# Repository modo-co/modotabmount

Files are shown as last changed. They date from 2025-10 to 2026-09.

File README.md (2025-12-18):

# Modo Tab Mount

**Smart tablet wall mount with ESPHome firmware, magnetic docking, and configurable smart features.**

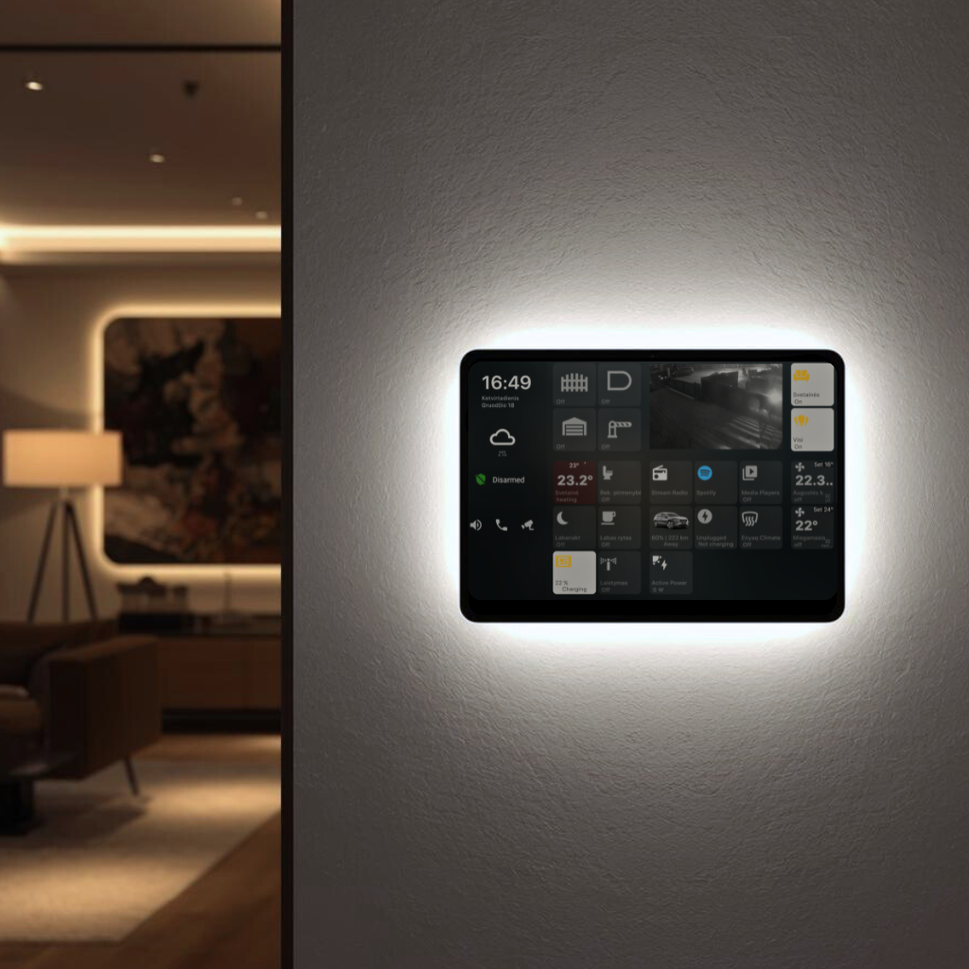
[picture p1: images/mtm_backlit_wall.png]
Modo Tab Mount – Wall mounted with ambient backlight


## Overview

**Modo Tab Mount** is a modular smart wall mount for tablets, designed for **standard flush EU electrical wall back boxes**.  
It combines a clean, floating design with integrated smart electronics and Home Assistant compatibility.

The project is suitable for **makers, home automation enthusiasts, and developers** who want a customizable and extensible tablet mounting solution.

## Features

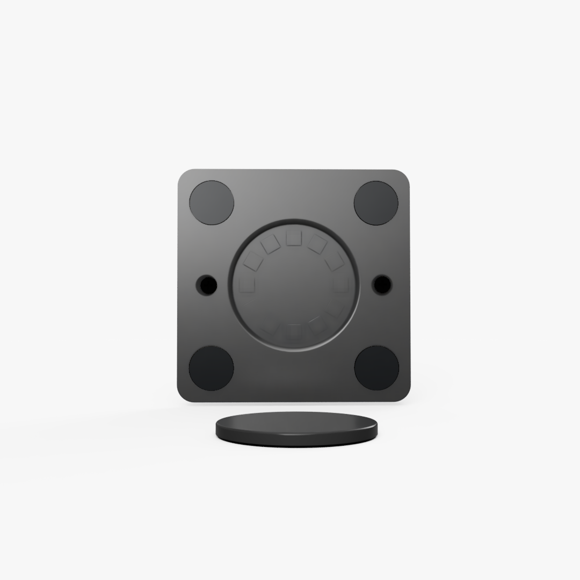
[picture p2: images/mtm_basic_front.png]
Modo Tab Mount – Front view


- **Magnetic Docking** – Secure, strong, snap-on mounting without mechanical locks  
- **Floating Design** – Minimal gap between tablet and wall  
- **Integrated Smart Power Supply** – 5V output for tablet charging and peripherals  
- **ESP32-based Controller** – Runs ESPHome firmware  
- **Backlit LEDs** – Optional WS2812B addressable LED bracket for status or ambient light  
- **Home Assistant Ready** – Native integration via ESPHome  
- **Expandable** – Support for additional sensors and peripherals  

## Hardware Components

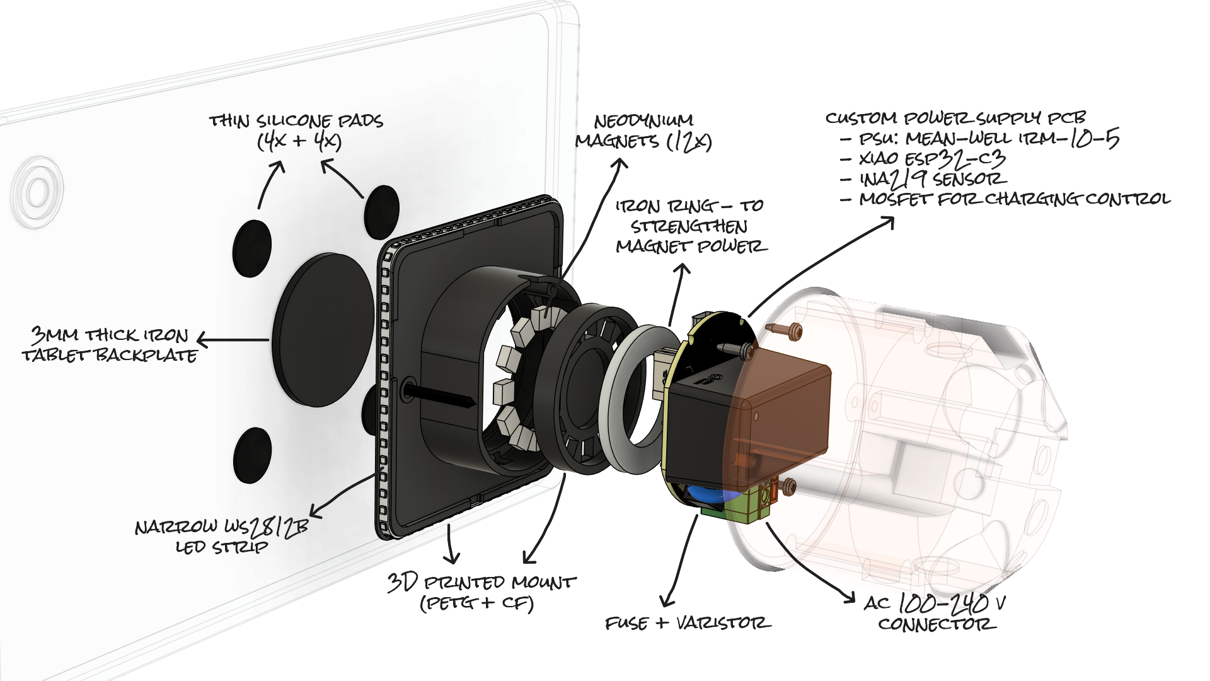
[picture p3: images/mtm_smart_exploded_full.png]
Modo Tab Mount – Exploded view


| Component | Description |
|---|---|
| Wall Box Mount | 3D-printed (PETG + CF filament) enclosure with embedded neodymium magnets / iron ring |
| Tablet Plate | 3 mm solid iron plate, attached using 3M VHB tape |
| Power Supply | Mean Well IRM-10-5 (5 V, 2 A) |
| PCB | Custom PCB for power distribution and peripheral connections |
| Microcontroller | Seeed Studio XIAO ESP32-C3 |
| LEDs | 2.7 mm WS2812B addressable LED strip |
| Charging Cable | Flat FPC cable with USB-C, Lightning, or Micro-USB connector |

## Repository Content

| Folder / File | Description |
|---|---|
| `PCB/` | Schematics and BOM for the custom PCB |
| `Docs/` | Installation instructions, datasheets, and technical documentation |
| `Images/` | Photos and diagrams |
| `modotabmount.yaml` | ESPHome firmware configuration |
| `README.md` | Project overview |
| `LICENSE` | License information |

## 📦 Firmware

**Modo Tab Mount** firmware runs on an **ESP32-C3** and is built using **ESPHome**.  
It provides charging control, power monitoring, Full LED RGB control with multiple built-in effects, and Home Assistant integration.

- Firmware is distributed as a **precompiled binary (`.bin`)** via **GitHub Releases**
- OTA updades with new firmware releases available
- End users **do not need to install ESPHome or compile firmware**
- ESPHome YAML file is included **for reference and advanced customization**

### 🔌 Smart Charging Control

- PWM-regulated 5V output for controlled tablet charging  
- Charging can be enabled or disabled remotely  
- During prolonged charging in a confined wall box, the power supply may warm up; firmware logic reduces or pauses charging to prevent excessive temperatures  

Charging state is exposed as a readable status  
(e.g. *Normal*, *Thermal throttling*, *Cooling down*).

### ⚡ Power & Energy Monitoring

An onboard **INA219** sensor measures:

- PSU Output voltage  
- PSU Output current  
- 30-second averaged values for stable reporting  

All values are available in **Home Assistant** and via the **built-in web interface**, enabling automations.

### 💡 LED Feedback & Ambient Lighting

Integrated **WS2812B LED strip** provides functional feedback and ambient lighting:

- Visual indication during **Wi-Fi access-point setup mode**
- Full RGB control with multiple built-in effects
- Automatic LED dimming during charging
- LED behavior configurable via Home Assistant or the local web interface

### 🌐 Connectivity & Interfaces

- Native **Home Assistant API** (ESPHome)
- Built-in **web interface** for local control and diagnostics
- **OTA firmware updates**
- **Bluetooth Proxy** support to extend Home Assistant BLE coverage

### ⚙️ Configuration & Diagnostics

User-configurable parameters include:

- Maximum temperature threshold
- Thermal throttle strength
- LED brightness during charging

Built-in diagnostics expose:

- Wi-Fi signal strength
- Device uptime
- Internal temperature
- Memory usage

A software-triggered factory reset is also available.

### 🔧 Advanced Usage

Advanced users may adopt device in ESPHome Builder, change YAML configuration and build custom firmware versions. 

---

## ⚠️ Safety Notice

This project involves **mains voltage (110–230 V AC)**.  Installation must be performed by qualified persons only.  

## 🏷 Commercial Product Note

This repository documents the **Modo Tab Mount project** and provides reference designs, firmware, and documentation intended for **makers and developers**.

A **commercially assembled Modo Tab Mount device**  offered separately by **MB Modoco**.  
Commercial units are:

- Assembled and tested by the manufacturer  
- Supplied with preinstalled firmware  
- Intended for end-user installation  
- Placed on the market under applicable EU conformity requirements  

The open-source materials in this repository are provided **for reference and non-commercial use** as defined by the applicable licenses.

## License

### Hardware (3D Models, Schematics, PCB Layouts)
Hardware designs in this repository are licensed under the  
**Creative Commons Attribution-NonCommercial 4.0 International (CC BY-NC 4.0)** license.

You may share and adapt these materials for **personal or educational use**.  
**Commercial manufacturing or resale is not permitted under this license.**

Full license text:  
https://creativecommons.org/licenses/by-nc/4.0/
### Firmware / Software
All firmware and software in this repository are licensed under the **MIT License**,  
allowing use, modification, and distribution, including for commercial purposes.

See the [LICENSE](./LICENSE) file for details.

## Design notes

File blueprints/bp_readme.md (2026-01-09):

## Tablet Charging Control

Automatically turns tablet charging **ON** when battery is low and **OFF** when
battery is high. Designed for wall-mounted tablets and smart chargers.

**Default behavior**
- Charging ON at **≤ 20%**
- Charging OFF at **≥ 80%**



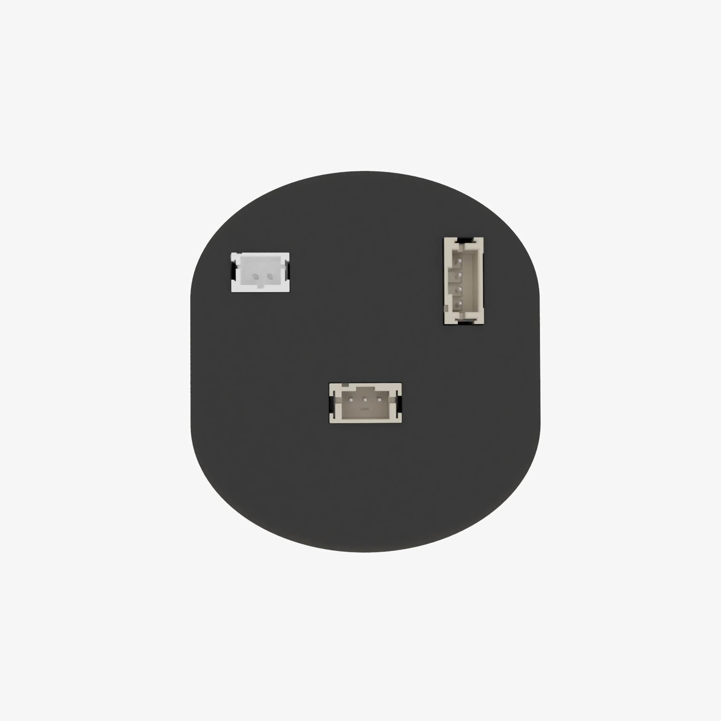
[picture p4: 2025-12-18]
images/psu_top.png

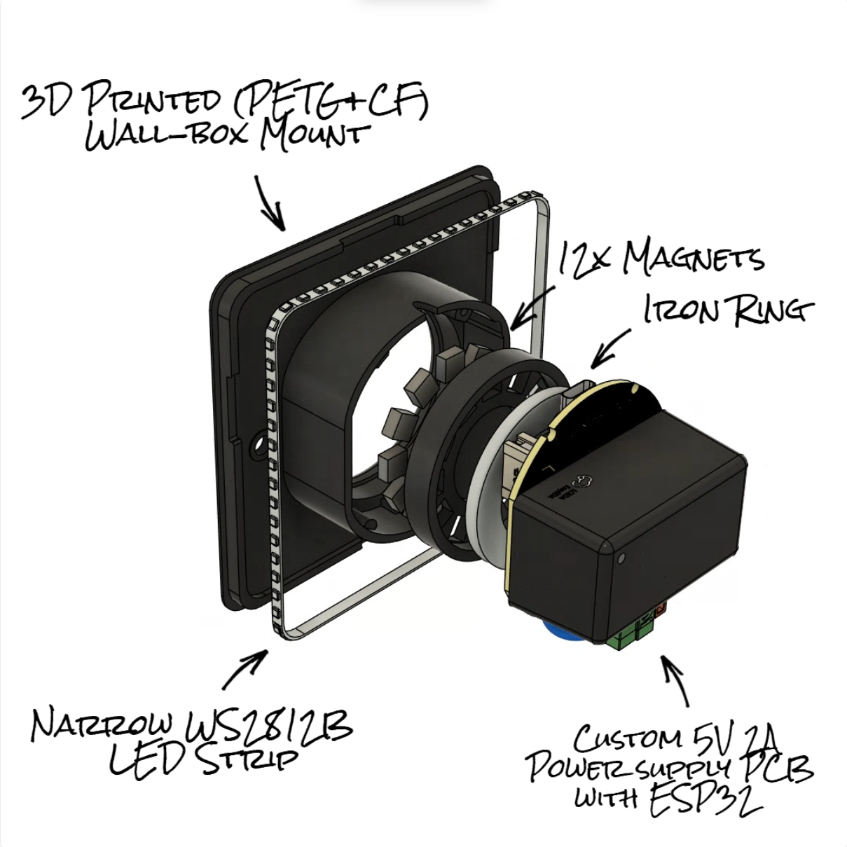
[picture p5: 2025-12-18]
images/mtm_smart_exploded.png

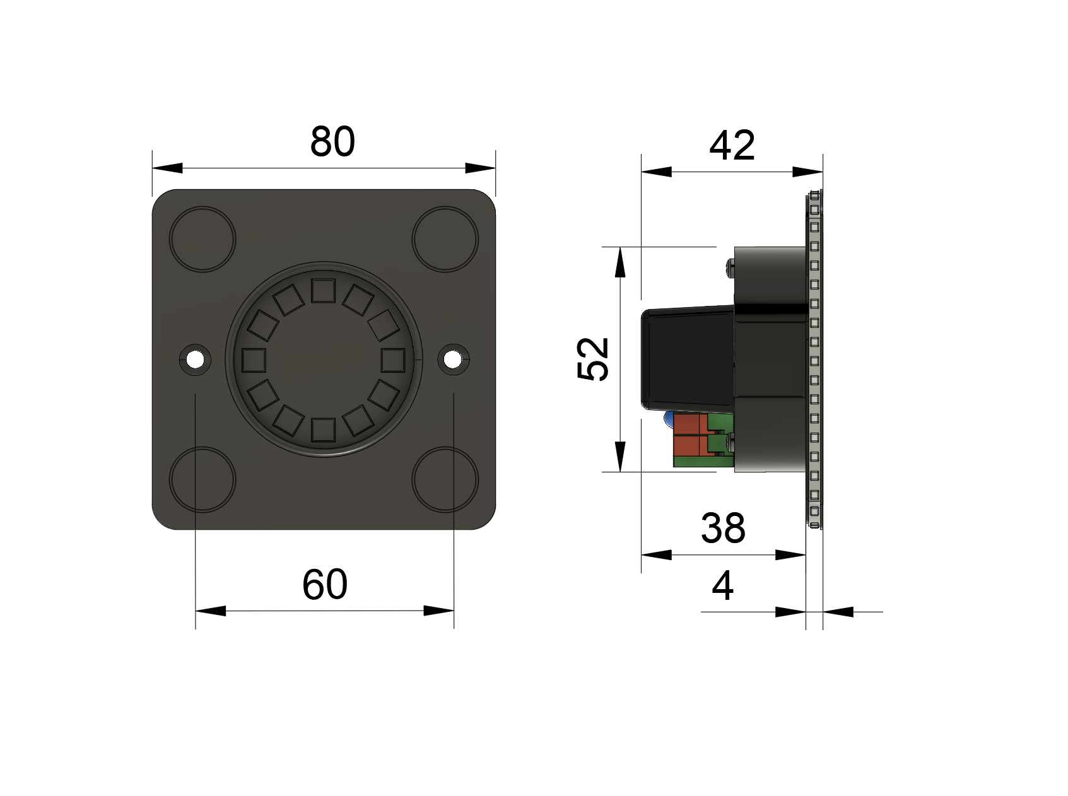
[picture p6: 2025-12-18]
images/mtm_smart_5.png

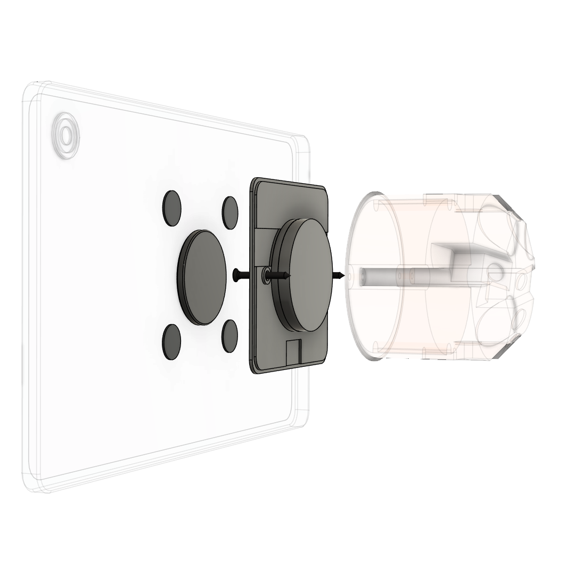
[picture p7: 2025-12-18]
images/mtm_basic_shaded.png

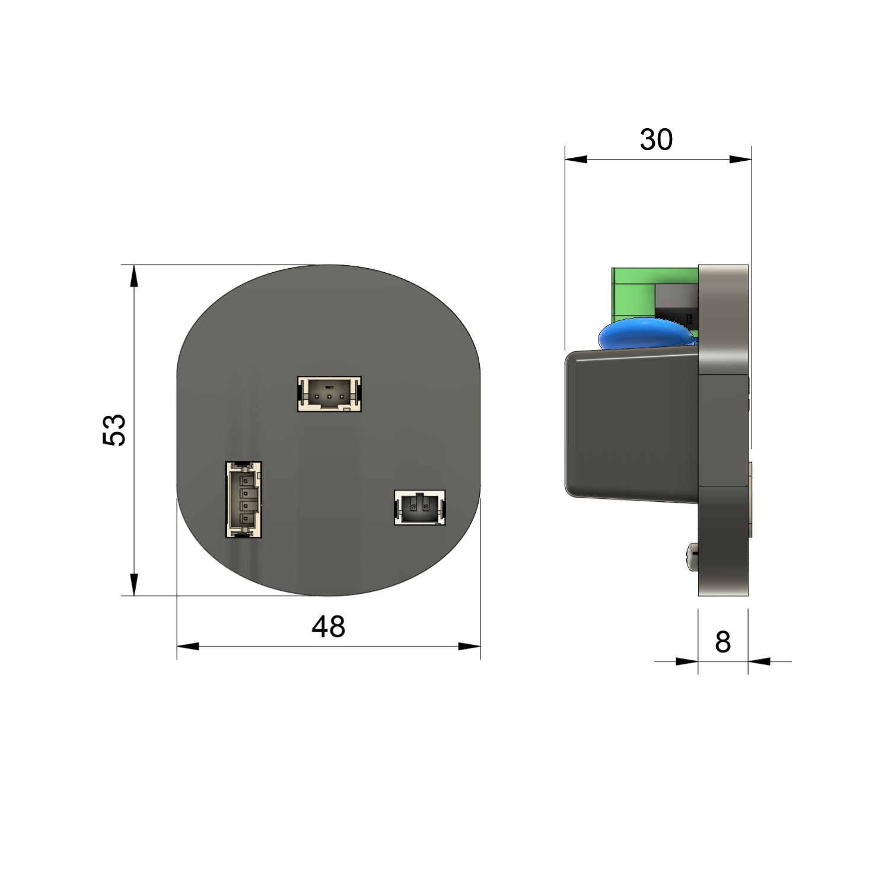
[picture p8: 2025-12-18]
images/psu_dimmensions.png

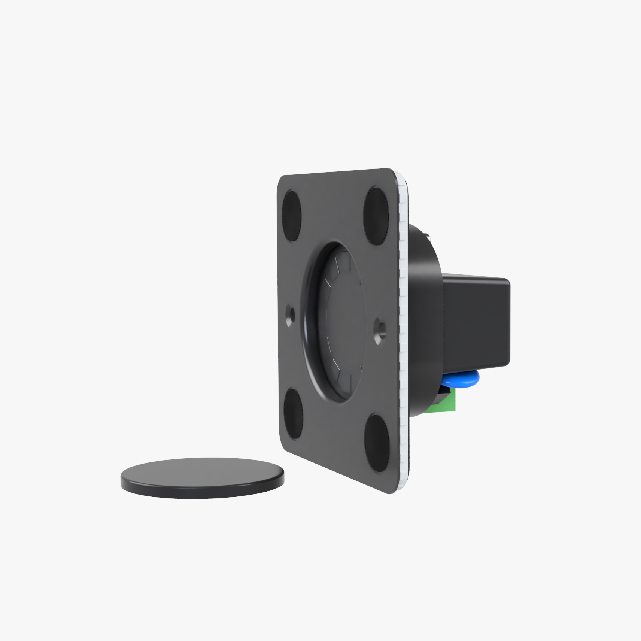
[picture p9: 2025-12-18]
images/mtm_smart_1.png

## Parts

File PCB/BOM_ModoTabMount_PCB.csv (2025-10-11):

ID | Name | Designator | Footprint | Quantity | Manufacturer Part
1 | XIAO ESP32C3 | U4 | COMM-SMD_KQ-2801_V106 | 1 | XIAO ESP32C3
2 | INA219AIDCNR | U2 | SOT-23-8 | 1 | INA219AIDCNR
3 | 10Kê | R1,R3 | 0805 | 2 | TC0550F1002T5E
4 | 0.1 | R5 | 2512 | 1 | MA251220JR100FZ
5 | 100nF | C1 | 0805 | 1 | 0805F104M101NT
6 | PH-4P | CONP_4PIN | CONN-SMD_PH2.0-4P | 1 | PH-4P
7 | 2.0-3P SMD 3P | CON_LEDS | CONN-SMD_3P-LT | 1 | PH-3P??
8 | AO3401A | Q1 | SOT-23_L2.9-W1.3-P1.90-LS2.4-BR | 1 | AO3401A
9 | MMBT3904 | Q2 | SOT-23-3_L2.9-W1.3-P1.90-LS2.4-BR | 1 | MMBT3904(RANGE:100-300)
10 | WAFER-PH2.0-2PLB | CHARGING | CONN-TH_2P-P2.00_XUNPU_WAFER-PH2.0-2PLB | 1 | WAFER-PH2.0-2PLB
11 | KF142V-5.08-2P | CON_AC | CONN-TH_P5.08_KF142V-5.08-2P | 1 | KF142V-5.08-2P
12 | MST 2A 250V | F2 | FUSE-TH_L8.4-W4.3-P5.08-D1.0 | 1 | MST 2A 250V
13 | CNR-10D561K | R10 | RES-TH_L12.5-W5.5-P7.50-D0.8-S5.50 | 1 | CNR-10D561K
14 | IRM-10-5 | U1 | PWRM-TH_4P-L45.7-W25.4-P8.0 | 1 | IRM-10-5

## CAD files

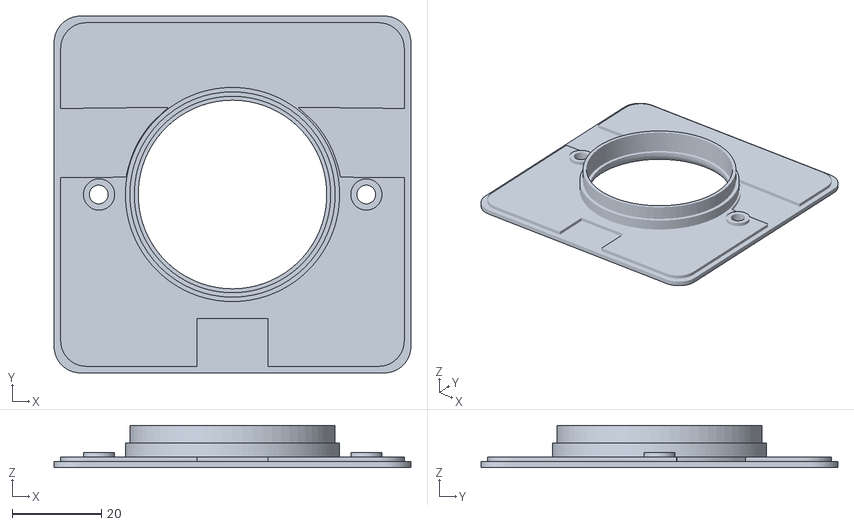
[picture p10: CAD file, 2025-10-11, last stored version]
3D_Models/mtm_plate_main.stl
80.0 x 80.0 x 9.50

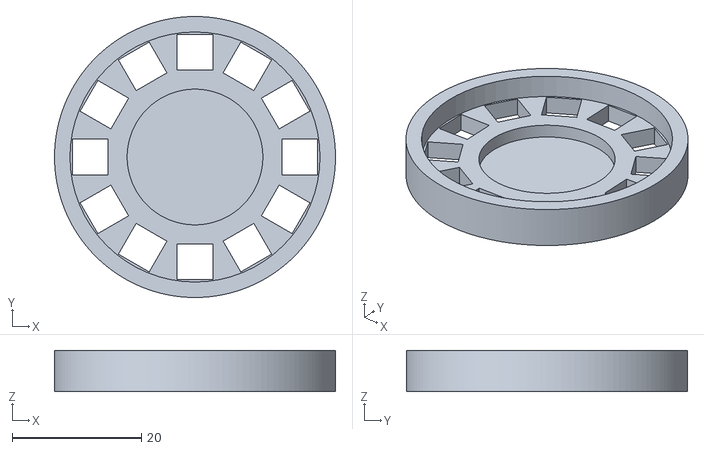
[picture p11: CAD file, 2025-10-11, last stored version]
3D_Models/mtm_plate_middle.stl
43.5 x 43.5 x 6.40

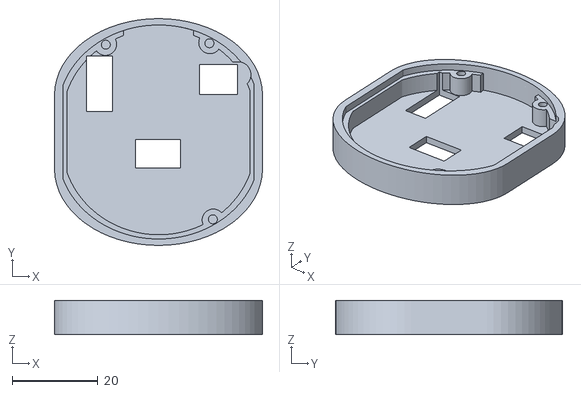
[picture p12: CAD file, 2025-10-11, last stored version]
3D_Models/mtm_psu.stl
48.6 x 53.0 x 8.00

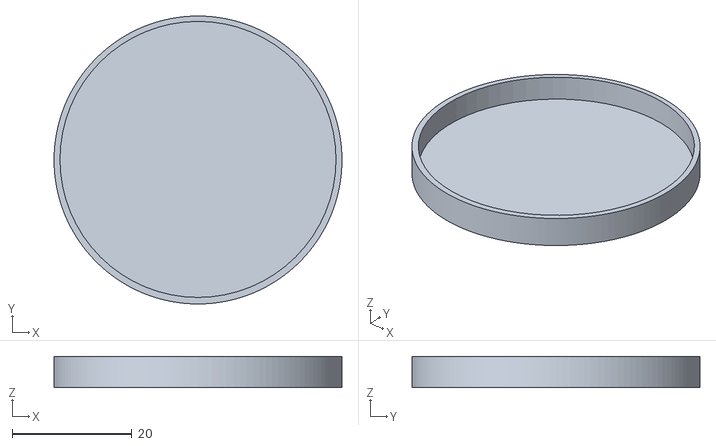
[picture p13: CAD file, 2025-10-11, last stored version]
3D_Models/mtm_plate_cap.stl
48.0 x 48.0 x 5.20

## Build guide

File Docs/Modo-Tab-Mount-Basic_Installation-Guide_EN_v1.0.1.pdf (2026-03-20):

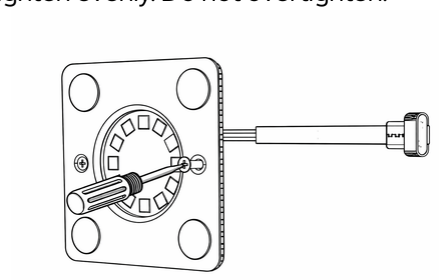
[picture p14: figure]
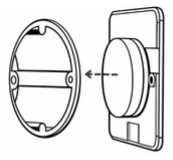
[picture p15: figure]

6.2.4. Ensure only the required cable length remains outside the wall.
6.2.5. Connect the charging cable to the tablet.
6.2.6. Attach the tablet to the mount.
6.2.7. The tablet will magnetically engage and lock into position.

# Modo Tab Mount Basic

## MTM-BASIC-EU

# Installation Guide & User Manual

## 1. Product Description

Modo Tab Mount Basic is a magnetic, wall-mounted tablet holder designed for clean and minimal tablet installations.

© 2025 Modoco | Designed and assembled in EU
www.modoco.io

## 2. Intended use

Modo Tab Mount Smart is intended for:

## 3. Safety Information

## 4. Before Installation

Ensure that:

## 5. Package Contents

Verify that the package contains the following items:

## 6. Installation Instructions

6.1.1. Clean the rear surface ofthe tablet using the supplied isopropyl.

### 6.1. Prepare the tablet

6.2.1. Align the wall mount with the installation box and the screw holes.

### 6.2. Install the Wall Mount

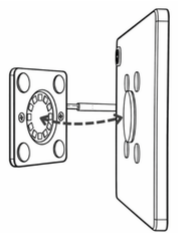
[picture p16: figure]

## 7. Normal operation

During normal operation, the tablet can be attached or removed by gently pulling it away from the wall.

## 8. Additional Information

Product contains no active electronics.
No power supply included.

## 9. Disposal & Environmental Information

This product must not be disposed of with household waste.
Dispose of electrical and electronic equipment in accordance with local regulations.

The mount provides a secure magnetic docking system and a floating tablet appearance while allowing a charging cable to be routed discreetly through the wall or surface-mounted cable channel.

- Indoor, dry-location installation
- Wall-mounted tablet charging and display
- Use with low-voltage consumer tablets
The product does not include a power supply or electronics.
- Installation involves mechanical mounting only.
- No connection to AC mains is required.
- Ensure the wall structure and installation box are suitable for the tablet weight.
- Intended for indoor, dry-location use only.
- A standard EU wall installation box is present and securely mounted.
- A suitable charging cable is available.
- The tablet is compatible in size (< 13'’) and weight (< 1.4 kg) with the mount.
1. Isopropyl alcohol cleaning pad
2. Tablet backplate (metal plate with adhesive)
3. Alignment template (for silicone pads and cable routing)
4. Silicone pads – 4 pcs
5. Magnetic wall box mount (passive, no electronics)
6. Self-tapping M3 mounting screws – 2 pcs
7. Adhesive primer applicator (single-use)
If any items are missing or damaged, do not install the product.

The product is designed for installation on standard EU wall installation back boxes and contains no active electronics or power components.

Charging behavior depends on the connected charger and tablet. No user interaction is required after installation.

6.1.3. Remove the protective film from the adhesive side of the tablet backplate.
6.1.4. Position the backplate centrally on the tablet and press firmly for at least 20 seconds. Initial handling strength is achieved immediately; full bond strength develops over 24–72 hours.
6.1.5. Place the alignment template over the installed backplate.
6.1.6. Remove the protective film from the silicone pads and attach one pad to each corner indicated on the template.
6.1.7. Place the alignment template over the installed backplate.
6.1.8. Remove the protective film from the silicone pads and attach one pad to each corner indicated on the template.
6.1.9 Remove the template. The tablet is now prepared for mounting.
6.2.2. Route the tablet charging cable through the designated mount cutouts.
6.2.3. Insert the supplied screws and tighten evenly. Do not overtighten.

www.modoco.io

## 10. Manufacturer Information

MB MODOCO
Rytmečio 10, Kaunas 47491
Lithuania
info@modoco.io
6.1.2. (Optional – Recommended for best adhesion). Apply the supplied adhesive primer to the area where the backplate will be installed. Apply a thin, even layer using light strokes. Allow the primer to dry completely — typically ~5 minutes at room temperature. Do not exceed 60 minutes before proceeding.

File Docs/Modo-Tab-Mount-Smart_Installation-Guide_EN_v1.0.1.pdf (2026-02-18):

# Modo Tab Mount Smart

## MTM-SMART-EU

# Installation Guide & User Manual

## 1. Product Description

Modo Tab Mount Smart is a magnetic wall-mounted tablet holder
with an integrated smart power supply, ambient LED lighting, and
ESPHome firmware with native Home Assistant compatibility. | Ensure that no live voltage is present by using a multimeter or
| another appropriate testing device.
© 2026 Modoco | Designed and assembled in EU
www.modoco.io

## 2. Intended use

Modo Tab Mount Smart is intended for:

## 3. Safety Information

Installation involves connection to the AC mains and should be performed by a person with appropriate electrical knowledge.

## 4. Before Installation

Ensure that:

## 5. Package Contents

Verify that the package contains the following items:

## 6. Installation Instructions

6.1.1. Clean the rear surface ofthe tablet using the supplied isopropyl alcohol pad.
6.1.2. (Optional – Recommended for best adhesion). Apply the supplied adhesion promoter to the area where the backplate will be installed. Apply a thin, even layer using light strokes. Allow the primer to dry completely (~5 minutes; do not exceed 60 before installation).
6.1.3. Remove the protective film from the adhesive side of the tablet backplate.
6.1.4. Position the backplate centrally on the tablet and press firmly for at least 20 seconds. Initial handling strength is achieved immediately; full bond strength develops over 24–72 hours.
6.1.5. Place the alignment template over the installed backplate.
6.1.6. Remove the protective film from the silicone pads and attach one pad to each corner indicated on the template.
6.1.7 Remove the template.
6.1.8. The tablet is now prepared for mounting.

### 6.1. Prepare the tablet

6.2.1. Connect the Live (L) and Neutral (N) conductors to the corresponding terminals on the wall mount power supply.
6.2.2. Carefully place the wall mount into the wall installation box.
6.2.3. Insert the supplied screws and tighten evenly. Do not overtighten.
6.2.4. Route the charging cable through the wall plate cutout before fully tightening the screws.
6.2.5. Ensure only the required cable length remains outside the wall.
6.2.6. Connect the charging cable to the tablet.
6.2.7. Attach the tablet to the mount.
6.2.8. The tablet will magnetically engage and lock into position.

### 6.2. Install the Wall Mount

6.3.1. Restore mains power.
6.3.2. The LEDs will illuminate with a blue scanner effect, indicating Wi-Fi setup (Access Point mode).
6.3.3. On a smartphone, tablet, or computer, search for the Wi-Fi network: modotabmount-xxxxxx

### 6.3. Wi-Fi Setup

## 7. Device controls & Integration

## 8. Normal operation

### 7.1 Control Interfaces

- The built-in Web User Interface (local access)
- Home Assistant via native ESPHome integration

Modo Tab Mount Smart can be monitored and controlled using:

### 7.2 Web User Interface

The built-in Web User Interface (Web UI) is accessible from a web browser on the same local network. Access the interface using the device’s IP address or by navigating to http://modotabmount-xxxxx.local

### 7.3 Home Assistant Integration

Modo Tab Mount Smart integrates natively with Home Assistant using ESPHome. Once added, the device appears as a standard ESPHome node and exposes its entities directly to Home Assistant.
To add Modo Tab Mount Smart to Home Assistant:
1. Ensure Home Assistant and the device are connected to the same local network.
2. After Wi-Fi setup is completed, Home Assistant will automatically discover the device.
3. A notification will appear in Home Assistant: “New ESPHome device discovered”
4. Select the device and confirm the integration.
If automatic discovery is disabled, the device can be added manually:
1. Open Settings → Devices & Services in Home Assistant.
2. Select Add Integration.
3. Choose ESPHome.
4. Enter the device’s IP address or hostname and confirm.
Once added, the device is ready to be used in dashboards and automations.

### 7.4 Available Functions and Entities

Both Web UI and Home Assistant Integration provide charging control, power monitoring (voltage, current, power), LED control (including color, brightness, effects), device and Wi-Fi status, and firmware management including restart, factory settings reset and over-the-air updates.

During normal operation, the tablet charges when mounted on the device. Tablet can be attached or removed by gently pulling it away from the wall. Device operates automatically once configured and does not require user interaction for basic operation.
Optional monitoring, control, and automation are available via Home Assistant or local Web User Interface.

## 9. Additional Information

Intended for indoor use only
Nominal input: AC 110–230 V~

, 50/60 Hz
Output: 5 V DC, max. 2 A (10 W)
Product contains no batteries

## 10. Disposal & Environmental Information

This product must not be disposed of with household waste.
Dispose of electrical and electronic equipment in accordance with local regulations.

## 11. Manufacturer Information

MB MODOCO
Rytmečio 10, Kaunas 47491
Lithuania
info@modoco.io

www.modoco.io

The product is designed for installation into standard EU flush wall installation boxes. All electronics, including the power supply and controller, are concealed within the wall, providing a clean, floating tablet appearance without obstructing speakers, buttons, or microphones.

- Indoor, dry-location installation
- Wall-mounted tablet charging and display
- Use with low-voltage consumer tablets
The product is not intended for outdoor use, wet environments, or life-critical applications.
- Disconnect mains power before installation or servicing.
- Use only within the rated input voltage: AC 110–230 V, 50/60 Hz.
- Install the product in accordance with applicable local electrical regulations.
Intended for indoor, dry-location use only.
- A standard EU wall installation box is present and securely mounted.
- Live (L) and Neutral (N) conductors are available inside the wall box.
- Adequate Wi-Fi signal strength is available at the installation location.
- The tablet is compatible in size (< 13'’) and weight (< 1.4 kg) with the mount.
1. Isopropyl alcohol cleaning pads
2. Tablet backplate (metal plate with pre-applied adhesive)
3. Alignment template (for silicone pads placement)
4. Silicone pads – 4 pcs
5. Magnetic wall box mount with integrated power supply and charging cable
6. Self-tapping M3 mounting screws – 2 pcs
7. Single-use adhesion promoter applicator
If any items are missing or damaged, do not install the product.

Note: xxxxx is a unique identifier assigned to each device.
6.3.4. Connect to the network.
- A “Sign in to network” notification will appear.
- If not, open a web browser and navigate to:
http://192.168.4.1
6.3.5. Select your home Wi-Fi network, enter the password, and confirm.
6.3.6. Upon successful connection, the LEDs will blink green three times.

Note: xxxxx is a unique identifier assigned to each device.

## Follow the numbered figures in order

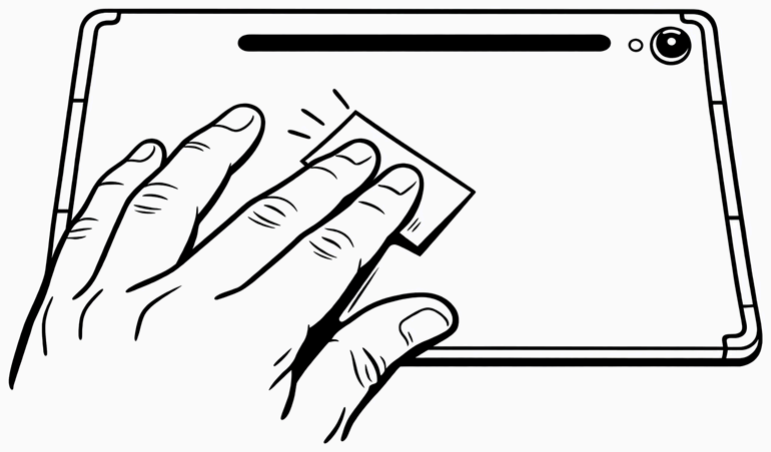
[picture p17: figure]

### Figure 1 - Clean the tablet back (see section 6.1.1)

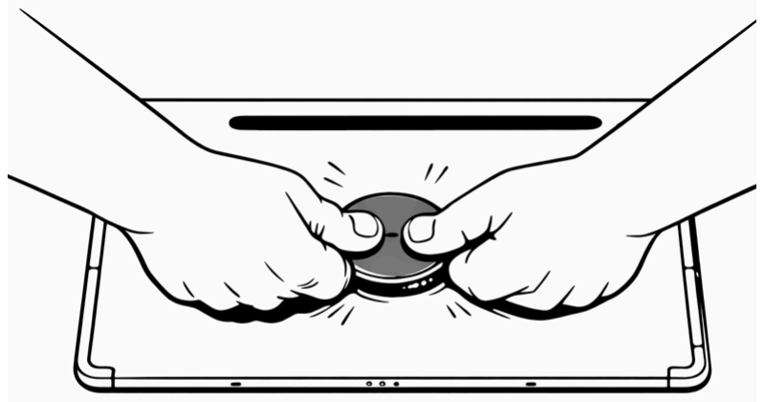
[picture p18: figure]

### Figure 2 - Attach metal backplate (see sections 6.1.2

- 6.1.3)

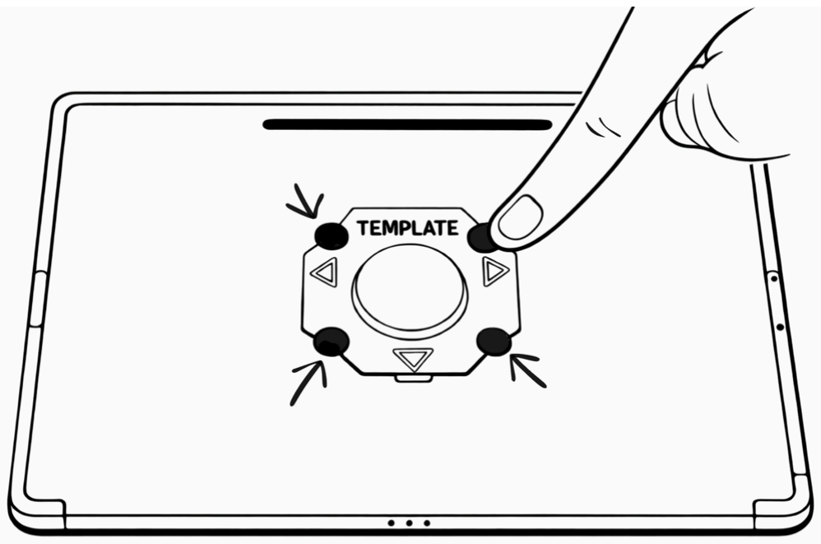
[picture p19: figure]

### Figure 3 - Place alignment template and attach silicone pads (see sections 6.1.4 - 6.1.5)

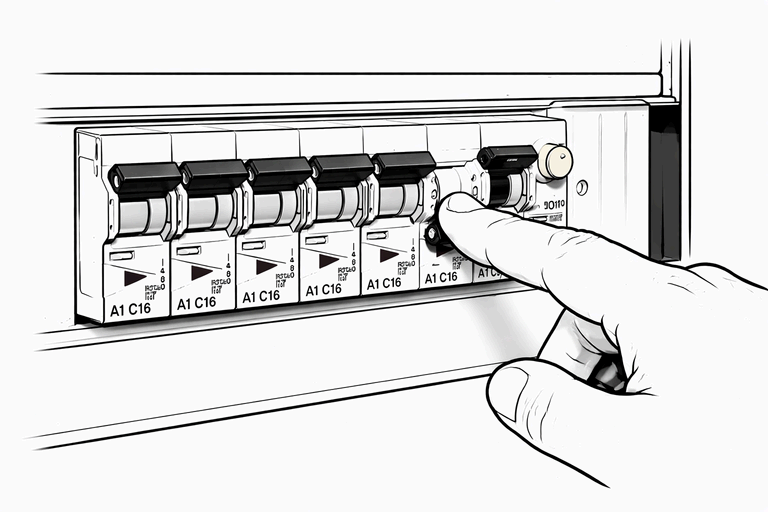
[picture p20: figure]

### Figure 4 - Disconnect mains power before installation

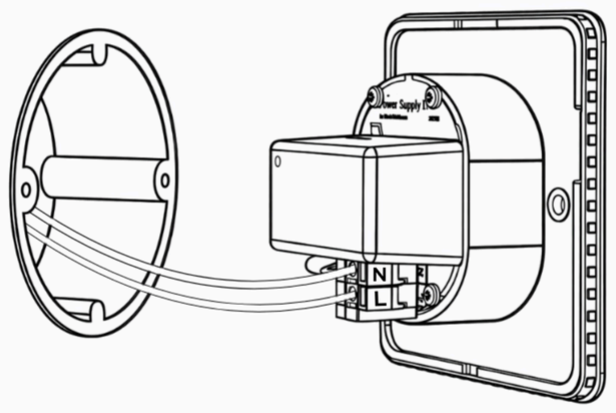
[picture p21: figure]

### Figure 5 - Connect AC supply wires (see section 6.2.1)

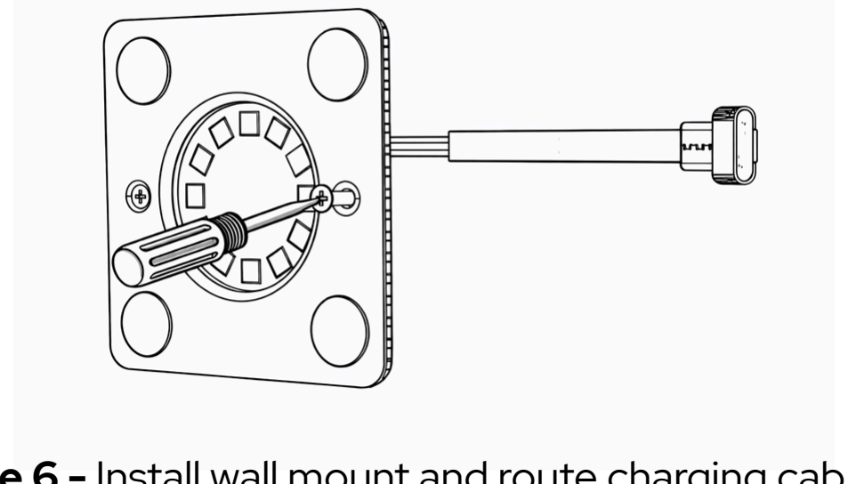
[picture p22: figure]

### Figure 6 - Install wall mount and route charging cable (see sections 6.2.2 - 6.2.5)

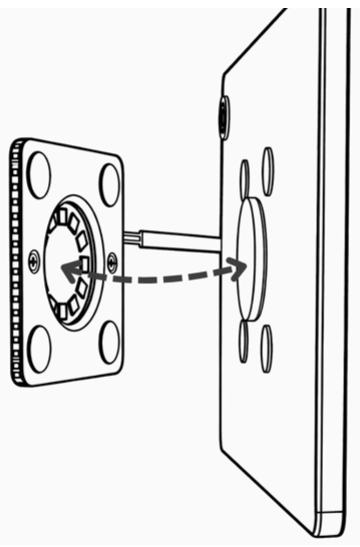
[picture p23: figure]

### Figure 7 - Connect Charging cable to the Tablet and dock it to the mount (see sections 6.2.6 - 6.2.8)

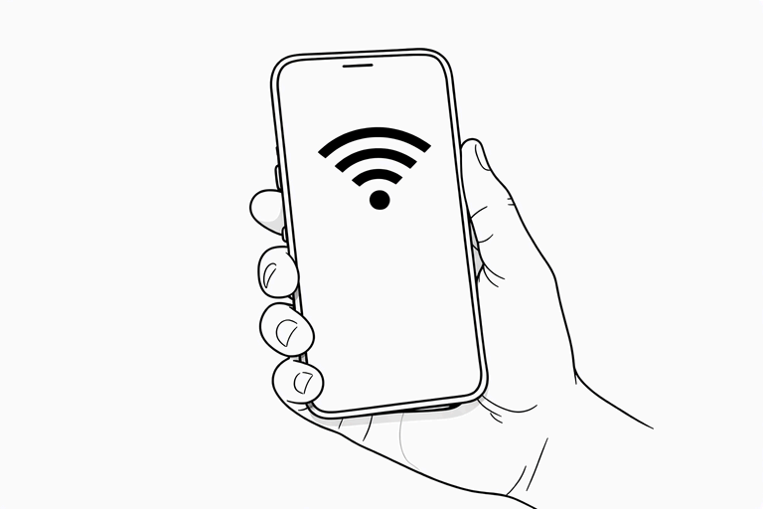
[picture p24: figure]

### Figure 8 - WIFI Setup (see section 6.3)

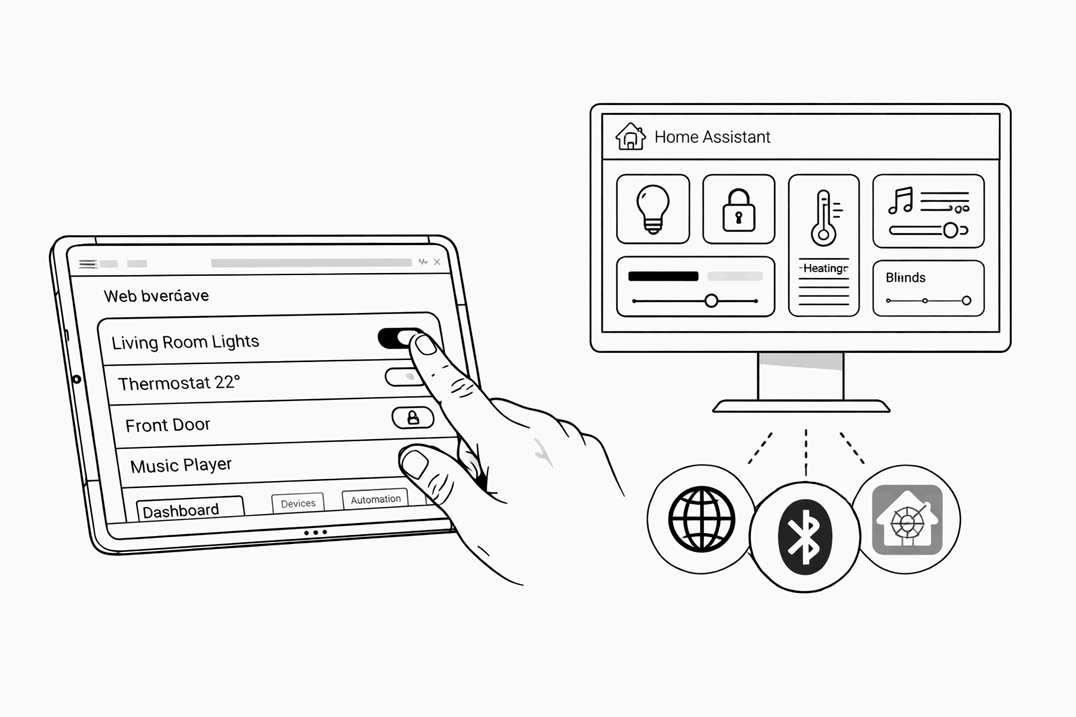
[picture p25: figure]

### Figure 9 - Device controls and integration (see section 7)

# Modo Tab Mount Smart

## MTM-SMART-EU

# Quick Start Guide (Illustrated)

© 2026 Modoco | Designed and assembled in EU
www.modoco.io

www.modoco.io

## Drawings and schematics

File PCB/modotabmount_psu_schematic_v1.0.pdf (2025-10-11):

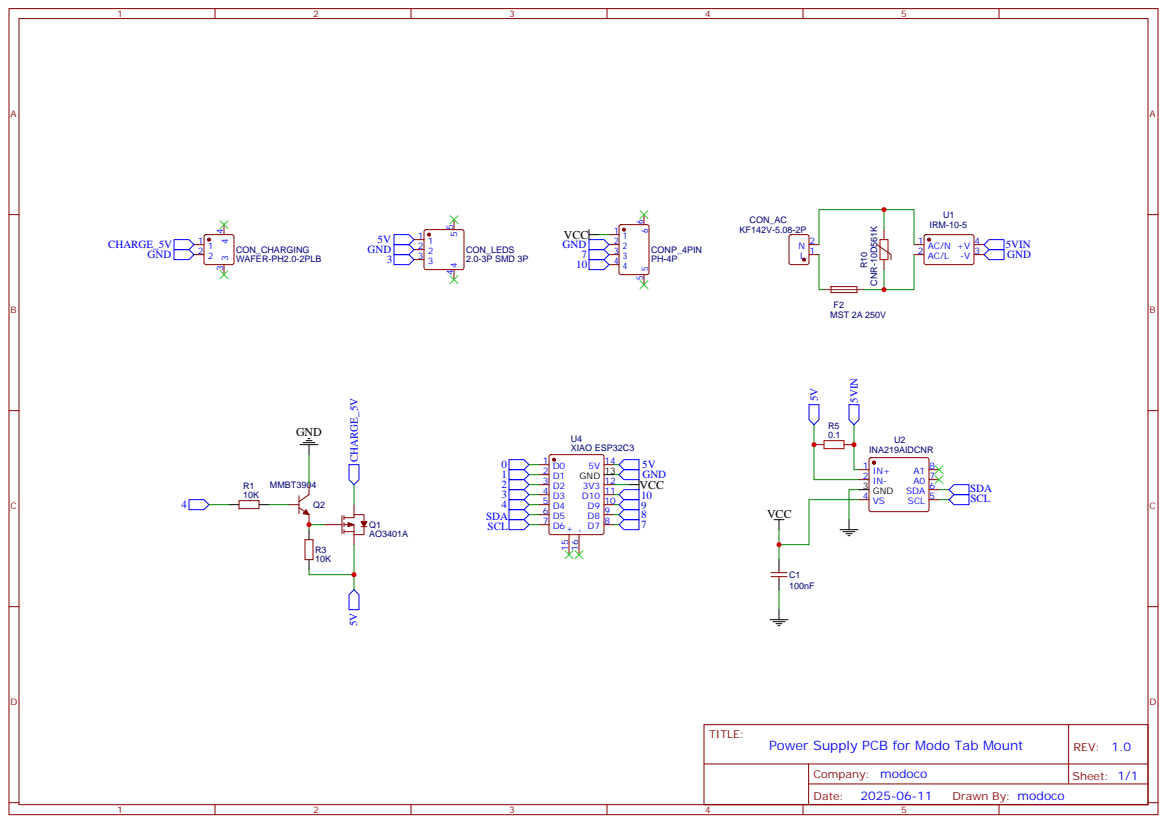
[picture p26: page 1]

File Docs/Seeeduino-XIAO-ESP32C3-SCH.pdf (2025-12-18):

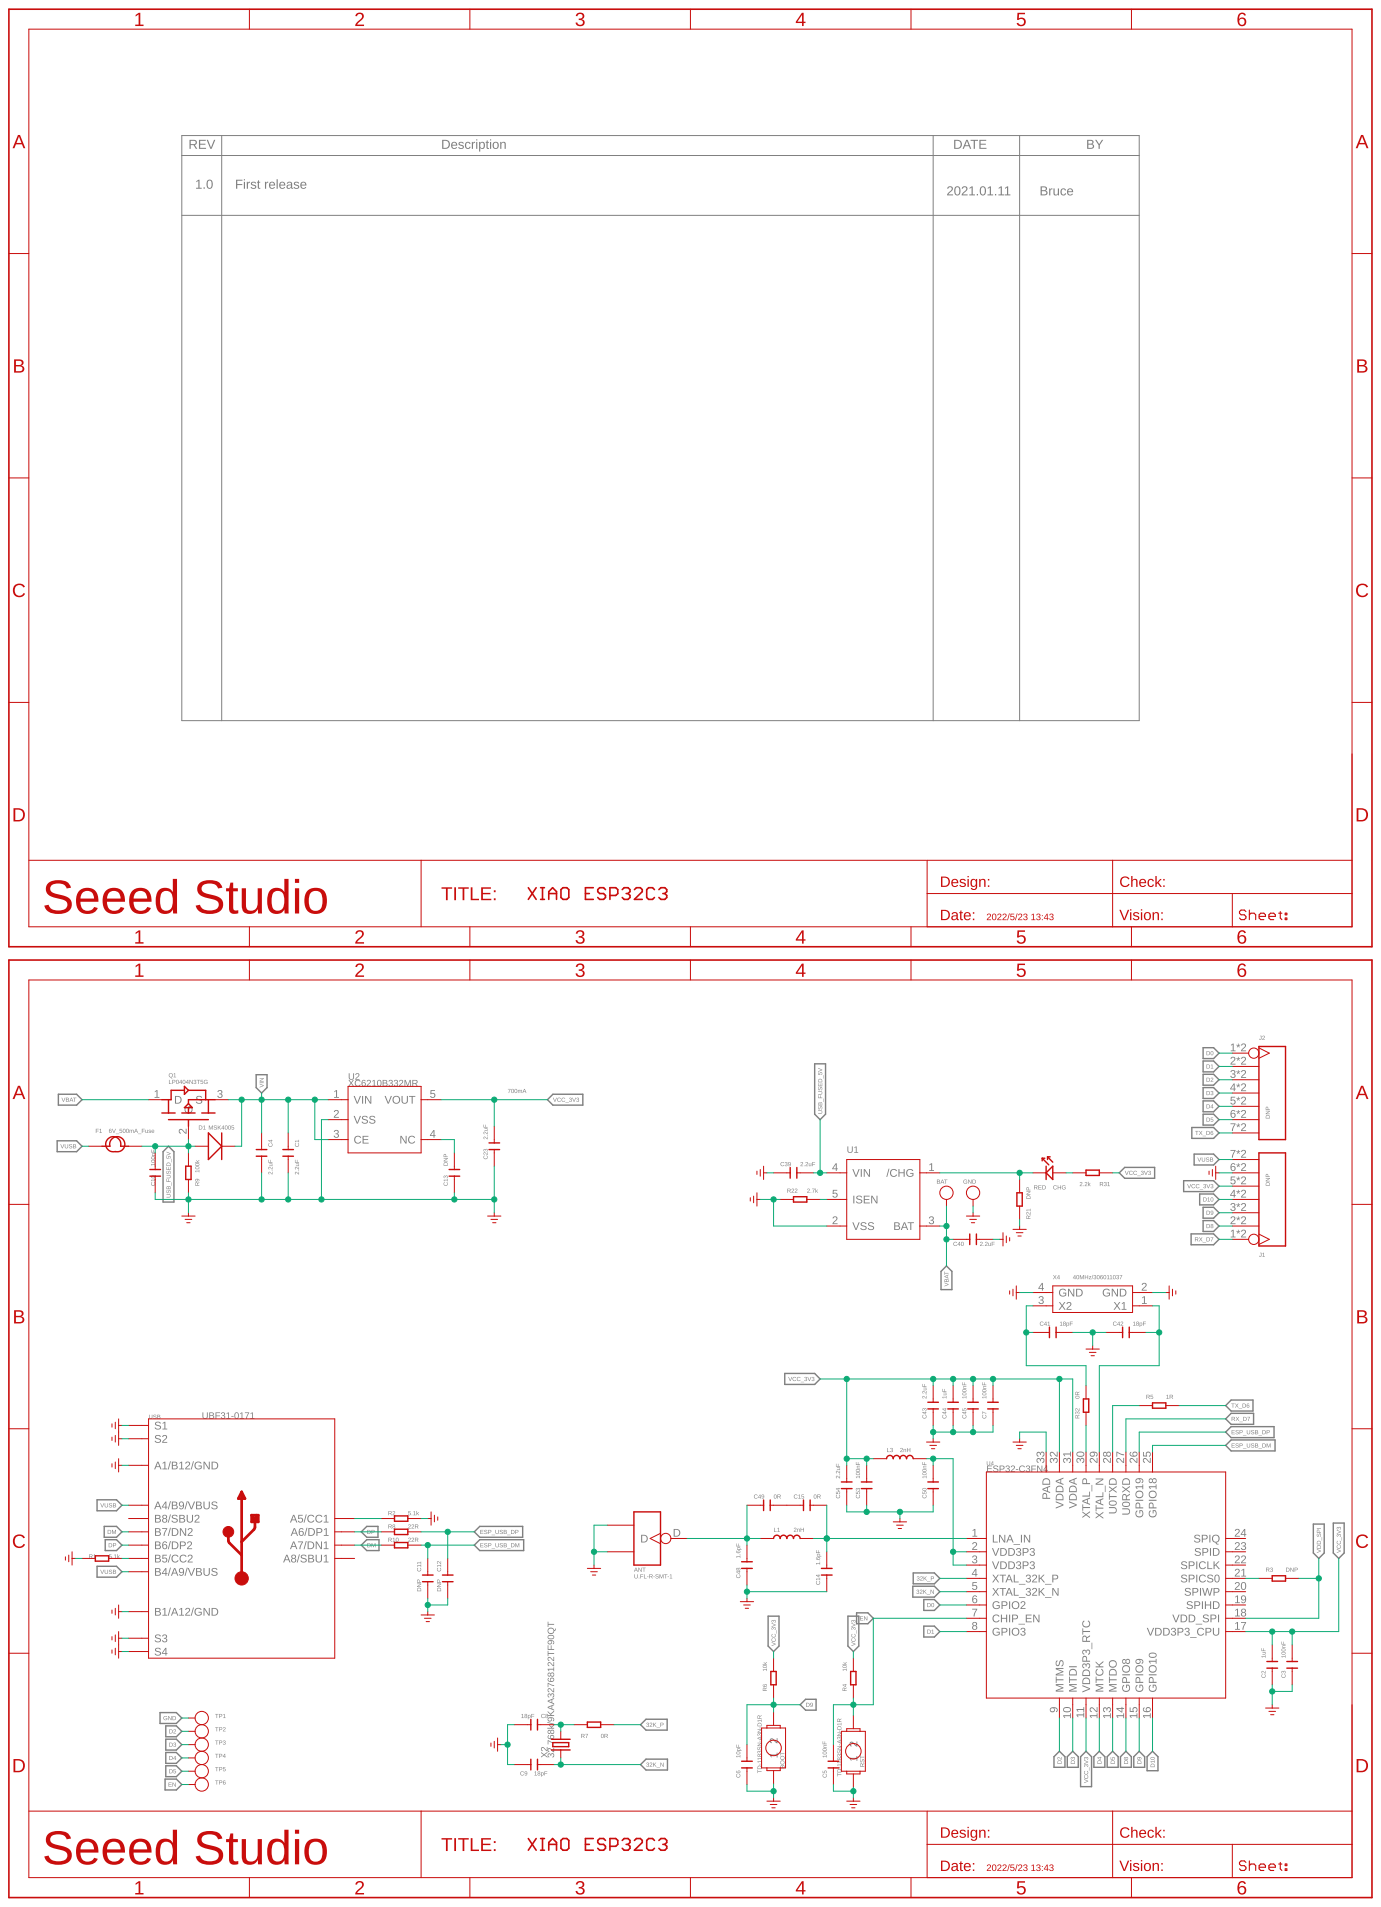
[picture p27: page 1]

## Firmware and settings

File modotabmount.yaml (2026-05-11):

esphome:
  name: modotabmount
  friendly_name: Modo Tab Mount
  name_add_mac_suffix: true

  on_boot:
    - priority: 250.0
      then:
        - lambda: |-
            // Check if there are ANY credentials stored in the WiFi component
            if (wifi::global_wifi_component->get_sta().get_ssid().empty()) {
              ESP_LOGI("main", "Factory state detected: No WiFi credentials. Starting scanner.");
              id(led_ap_mode).execute();
            } else {
              ESP_LOGI("main", "Credentials found. Waiting for WiFi connection...");
            }

esp32:
  board: esp32-c3-devkitm-1
  variant: esp32c3
  framework:
    type: esp-idf
    sdkconfig_options:
      CONFIG_ESP_TASK_WDT_TIMEOUT_S: "10"
  
logger:
  
debug:
  update_interval: 10s

network:
  enable_high_performance: true

mdns:
  id: my_mdns

api:
  reboot_timeout: 0s

wifi:
  ap:
  power_save_mode: none
  on_connect:
    then:
      - logger.log: "WiFi connected"
      - script.execute: led_ap_mode_stop
      - script.execute: led_wifi_connected
           
captive_portal:

ota:
  - platform: esphome

web_server:
  port: 80
  version: 3
  log: false
  ota: false

esp32_ble:
  disable_bt_logs: true

bluetooth_proxy:
  id: bt_proxy
  active: false
  connection_slots: 1
  cache_services: false

i2c:
  sda: 7
  scl: 21
  scan: false

# --------------------------------------------------------------------
# Globals
# --------------------------------------------------------------------
globals: 
  - id: prev_led_brightness
    type: float
    restore_value: no
    initial_value: '1.0'

  - id: last_charging_state
    type: bool
    restore_value: no
    initial_value: 'false'

  - id: power_accum
    type: float
    restore_value: no
    initial_value: '0.0'

  - id: current_accum
    type: float
    restore_value: no
    initial_value: '0.0'

  - id: voltage_accum
    type: float
    restore_value: no
    initial_value: '0.0'

  - id: sample_count
    type: int
    restore_value: no
    initial_value: '0'

  - id: led_clamp_active
    type: bool
    restore_value: no
    initial_value: 'false'

  # ownership to prevent clamp touching AP/WiFi feedback
  - id: led_mode
    type: int
    restore_value: no
    initial_value: '0'
    # 0 = user
    # 1 = ap_mode
    # 2 = wifi_feedback

# --------------------------------------------------------------------
# PWM output
# --------------------------------------------------------------------
output:
  - platform: ledc
    pin: 6
    id: tablet_pwm
    frequency: 1000 Hz

# --------------------------------------------------------------------
# ⚡ Charging control
# --------------------------------------------------------------------
switch:

  - platform: template
    name: "Bluetooth Enabled"
    id: bluetooth_switch
    optimistic: true
    restore_mode: ALWAYS_ON
    entity_category: config
    icon: "mdi:bluetooth-off"

    # When turned off, disable the BLE radio
    on_turn_off:
      then:
        - ble.disable:
        - logger.log: "Bluetooth radio disabled"

    # When turned on, enable the BLE radio on boot
    on_turn_on:
      then:
        - logger.log: "Bluetooth radio enabled - reboot"
  
  - platform: template
    id: tablet_charging
    name: "Tablet Charging"
    icon: "mdi:tablet-cellphone"
    optimistic: true

    # apply clamp immediately if LED already on
    on_turn_on:
      then:
        - script.execute: led_apply_clamp_deferred

    # restore user brightness when charging turns off
    on_turn_off:
      then:
        - lambda: |-
            if (!id(led_clamp_active)) return;

            if (id(addressable_led).current_values.is_on()) {
              auto call = id(addressable_led).turn_on();
              call.set_brightness(id(prev_led_brightness));
              call.perform();
            }

            id(led_clamp_active) = false;
            
# --------------------------------------------------------------------
# Addressable LED
# --------------------------------------------------------------------
light:
  - platform: esp32_rmt_led_strip
    id: addressable_led
    name: "LED"
    icon: "mdi:television-ambient-light"
    chipset: WS2812
    pin: GPIO5
    num_leds: 64
    rgb_order: GRB
    default_transition_length: 0s

    on_state:
      then:
        - script.execute: led_apply_clamp_deferred

    effects:
      - addressable_rainbow:
          name: Rainbow
      - addressable_color_wipe:
          name: Color Wipe
      - addressable_twinkle:
          name: Twinkle
      - addressable_scan:
          name: Scanner
          move_interval: 50ms
      - pulse:
          name: Pulse
          transition_length: 1000ms
          update_interval: 1000ms
      - pulse:
          name: Pulse Fast
          transition_length: 500ms
          update_interval: 500ms
      - random:
          name: Random Colors
      - addressable_scan:
          name: Energy Beam
          move_interval: 20ms
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

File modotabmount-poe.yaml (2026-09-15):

substitutions:
  name: modotabmount-poe
  friendly_name: Modo Tab Mount POE

  # TPS25751S I2C target address on the Unique Address Interface.
  tps25751_addr: "0x21"

esphome:
  name: ${name}
  friendly_name: ${friendly_name}
  name_add_mac_suffix: true

  # ====================== BOOT SEQUENCE ======================
  on_boot:
    - priority: 250.0
      then:
        - lambda: |-
            // Check if there are ANY credentials stored in the WiFi component
            if (wifi::global_wifi_component->get_sta().get_ssid().empty()) {
              ESP_LOGI("main", "Factory state detected: No WiFi credentials. Starting scanner.");
              id(led_ap_mode).execute();
            } else {
              ESP_LOGI("main", "Credentials found. Waiting for WiFi connection...");
            }
api:
  reboot_timeout: 0s

esp32:
  board: esp32-c3-devkitm-1
  variant: esp32c3
  framework:
    type: esp-idf
    sdkconfig_options:
      CONFIG_ESP_TASK_WDT_TIMEOUT_S: "10"

logger:
  hardware_uart: UART0
  baud_rate: 115200

debug:
  update_interval: 10s

network:
  enable_high_performance: true

mdns:
  id: my_mdns

wifi:
  ap:
  power_save_mode: none
  on_connect:
    then:
      - logger.log: "WiFi connected"
      - script.execute: led_ap_mode_stop
      - script.execute: led_wifi_connected
      - text_sensor.template.publish:
          id: bluetooth_status
          state: "Enabled (boot default)"
      - if:
          condition:
            lambda: 'return !id(ble_enabled);'
          then:
            - script.execute: delayed_ble_disable
            - logger.log: "Queued delayed BLE disable (45s after connect)"
          else:
            - logger.log: "Bluetooth enabled (default or user preference)"
            - text_sensor.template.publish:
                id: bluetooth_status
                state: "Enabled"

captive_portal:
ota:
  - platform: esphome

web_server:
  port: 80
  version: 3
  log: true
  ota: false

esp32_ble:
  disable_bt_logs: true

bluetooth_proxy:
  id: bt_proxy
  active: false
  connection_slots: 1
  cache_services: false

# ====================== I2C ======================
# Shared bus: INA219 power monitor + TPS25751S I2Ct target interface both
# sit on this bus per schematic (both explicitly tied to nets "SDA"/"SCL").
i2c:
  id: i2c_bus
  sda: GPIO4
  scl: GPIO5
  scan: true

# ====================== CHARGING (ALWAYS ON) ======================
switch:
  - platform: gpio
    pin: GPIO10
    id: tablet_charging
    name: "Tablet Power"
    internal: false
    disabled_by_default: true   # hidden in HA by default; user can enable via entity settings if ever needed
    icon: "mdi:battery-plus"
    # Always on - PoE variant must never drop tablet power, or the
    # Ethernet link (which shares the same port) drops too.
    restore_mode: ALWAYS_ON
    device_class: switch

  - platform: gpio
    pin: GPIO6
    id: ilim_low
    name: "Charging Limiter"
    internal: false
    inverted: true
    icon: "mdi:battery-sync"
    restore_mode: RESTORE_DEFAULT_OFF

  - platform: template
    name: "Bluetooth Enabled"
    id: bluetooth_switch
    lambda: 'return id(ble_enabled);'
    optimistic: false
    restore_mode: DISABLED
    entity_category: config
    icon: "mdi:bluetooth-off"
    turn_on_action:
      - lambda: 'id(ble_enabled) = true;'
      - logger.log: "Bluetooth radio enabled"
      - text_sensor.template.publish:
          id: bluetooth_status
          state: "Enabled - rebooting in 5 seconds"
      - delay: 5s
      - button.press: restart_button
    turn_off_action:
      - ble.disable:
      - lambda: 'id(ble_enabled) = false;'
      - logger.log: "Bluetooth radio disabled"
      - text_sensor.template.publish:
          id: bluetooth_status
          state: "Disabled"

# ====================== LED + SCRIPTS ======================
light:
  - platform: esp32_rmt_led_strip
    id: addressable_led
    name: "LED"
    icon: "mdi:television-ambient-light"
    chipset: WS2812
    pin: GPIO3
    num_leds: 64
    rgb_order: GRB
    default_transition_length: 0s
    effects:
      - addressable_rainbow:
          name: Rainbow
      - addressable_color_wipe:
          name: Color Wipe
      - addressable_twinkle:
          name: Twinkle
      - addressable_scan:
          name: Scanner
          move_interval: 50ms
      - pulse:
          name: Pulse
          transition_length: 1000ms
          update_interval: 1000ms
      - pulse:
          name: Pulse Fast
          transition_length: 500ms
          update_interval: 500ms
      - random:
          name: Random Colors
      - addressable_scan:
          name: Energy Beam
          move_interval: 20ms
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

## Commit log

2025-12-14 Expand README with firmware details and safety notice
    Added detailed firmware information and features for Modo Tab Mount.
2025-12-15 Add factory reset button configuration
2025-12-16 Add commercial product note for Modo Tab Mount
    Added a section about the commercial availability of the Modo Tab Mount device, including details on assembly, firmware, and intended use.
2025-12-17 Implement LED flash on WiFi connect
    Add WiFi connection event logging and LED flashing.
2025-12-18 Change LED flash count from 5 to 3
2025-12-18 Adjust delay time for LED indication
    Reduced delay time from 5 seconds to 1 second before flashing the LED.
2026-01-05 Update device info and remove web_server weight
    Removed web_server sorting_weight and added device name.
2026-01-05 Add disabled_by_default field to device configuration
2026-01-09 Refactor LED control and state management
    Refactor LED control logic for charging and Wi-Fi status. Introduce new scripts for LED effects and adjust global variables for better state management.
2026-01-09 Add Tablet Charging Control blueprint
    This blueprint automates tablet charging based on battery levels, turning charging ON below a specified minimum level and OFF above a specified maximum level.
2026-01-09 Create bp_readme.md for Tablet Charging Control
    Added a readme for the Tablet Charging Control blueprint with default behavior and import link.
2026-01-09 Update blueprint readme for tablet charging control
2026-01-10 Disable I2C scan and update addressable effects
    Disabled I2C scan and removed twinkle effect from addressable effects. Updated charging status publishing logic.
2026-01-10 Add BLE Proxy switch configuration
2026-01-10 Refactor BLE handling and LED indication logic
2026-01-10 Remove OTA-safe BLE handling and proxy switch
    Removed BLE handling and related configurations from the YAML file.
2026-02-26 Refactor Bluetooth and charging control logic
    Refactor Bluetooth and charging logic, enabling Bluetooth by default and updating related scripts. Added new global variables for Bluetooth status and control logic for charging.
2026-02-27 Refactor lambda expressions in template sensors
    Updated lambda syntax for template sensors to use multiline format.
2026-03-10 Add initial configuration for Modo Tab Mount LV
    Add configuration for Modo Tab Mount LV including WiFi, Bluetooth, and various sensors.
2026-03-10 Change LED pin from GPIO5 to GPIO3
2026-03-10 Implement shunt_multiplier for power and current adjustments
    Added shunt_multiplier for dynamic power and current calculations based on shunt resistance.
2026-03-10 Refactor shunt multiplier handling and resistance value
    Removed shunt multiplier logic and updated shunt resistance value.
2026-03-14 Add initial configuration for modotabmount device
2026-04-06 Refactor tablet charging and Bluetooth settings
    Updated GPIO pin for tablet charging and modified Bluetooth control logic. Removed unused charging power and thermal throttle ratio parameters.
2026-04-06 Add Bluetooth Status sensor to configuration
2026-04-06 Increase accuracy decimals for voltage and power
2026-04-06 Refactor charging logic and remove unused parameters
    Removed unused led_clamp_active and led_mode configurations. Updated tablet_charging switch to include logging on turn on/off. Added on_value logic for thermal management and status publishing.
2026-04-06 Refactor sensor configuration for template sensors
2026-05-11 Add reboot and watchdog timeout settings
    [modotabmount-sm.yaml]
2026-05-11 Add reboot_timeout and watchdog_timeout settings
    [modotabmount.yaml]
2026-05-11 Add reboot_timeout configuration to API settings
    [modotabmount-smart.yaml]
2026-05-27 Add Modo Tab Mount POE configuration
    Added configuration for Modo Tab Mount POE including boot sequence, I2C initialization, and various sensors and controls.
2026-07-20 Change number of LEDs from 64 to 72
2026-09-13 Refactor modotabmount-poe configuration
    Updated configuration for modotabmount-poe, including firmware update check and new factory reset button.
2026-09-15 Update modotabmount-poe.yaml with new configurations
    Added TPS25751S I2C target address and updated various configurations, including enabling logging and modifying sensor definitions.
2026-09-15 Rename power and current template sensors
